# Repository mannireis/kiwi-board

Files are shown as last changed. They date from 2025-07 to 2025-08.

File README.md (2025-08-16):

# Kiwi Board

Screenshot 2025-08-16 at 12-41-57 471098307-857b4444-1be0-49bc-9b43-69fed2567859 png (PNG Image 1916 × 1100 pixels)

The Kiwi Board is a 42-key split keyboard designed for stenographic input. It features a 3×6 column-staggered layout with 3 thumb keys per side.  
The design is based on the [Polyglot keyboard](https://stenokeyboards.com/products/polyglot-keyboard) and includes an integrated RP2040 microcontroller.

This project started after I discovered steno and wanted to build a keyboard tailored for learning and experimenting with chorded input.

---

## Specifications

- Layout: Split, 3×6 + 3 thumb keys per side
- Total keys: 42
- Switches: MX
- Microcontroller: RP2040 (integrated)
- Firmware: [RMK](https://rmk.rs/) — A feature-rich Rust keyboard firmware
- Intended use: Compatible with steno software (e.g. [Plover](https://www.openstenoproject.org/plover/))

---

## Images

### PCB




### Schematic



### Case
kiwi-top
kiwi-side
kiwi-closeup
kiwi-angled

---

## Bill of Materials (BOM)

| Item | Price | Notes |
|---|---|---|
| PCB | $83.78  | Ordered from JLCPCB |
| Keycaps | $9.90 | [AliExpress link](https://shorturl.at/fVK32) |
| Rubber Feet  | $3.84 | [AliExpress link](https://shorturl.at/bqHlW) |
| Switches | $32.72  | [Deltakey Co.](https://deltakeyco.com/) |
| diodes |  | i own them |
| hotswap sockets |  | i have them |
| **Total** | **$130.24** | |

---

## Firmware

The Kiwi Board uses [RMK](https://rmk.rs/), A feature-rich Rust keyboard firmware!

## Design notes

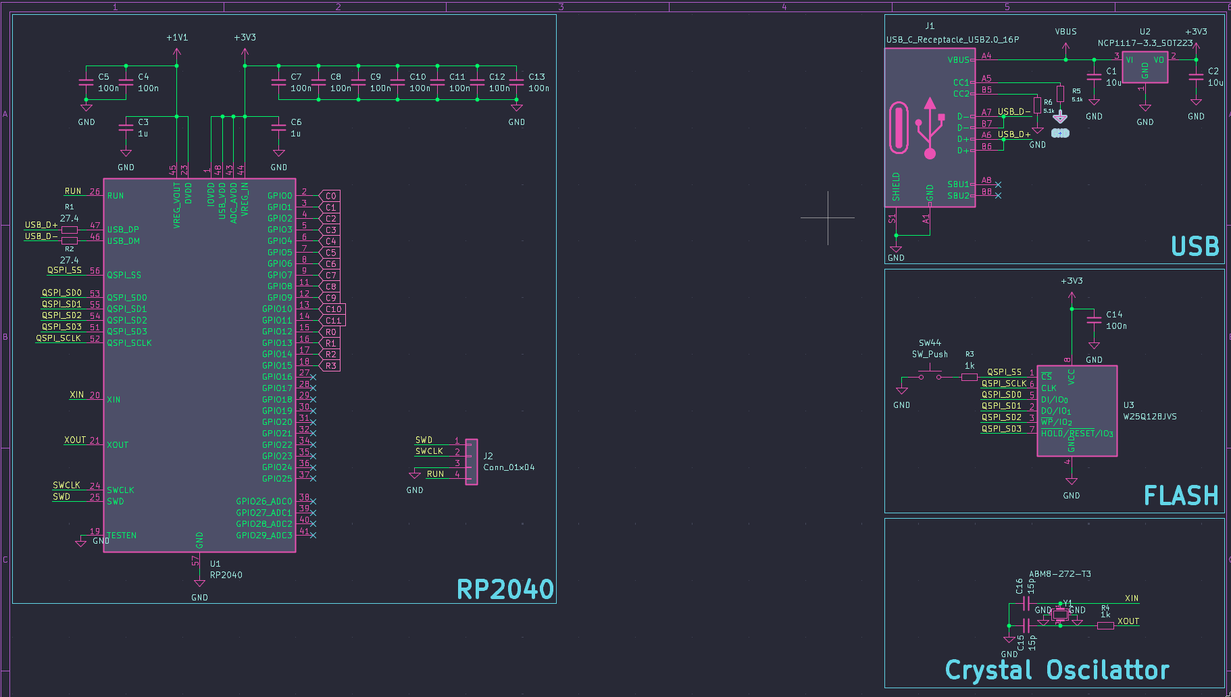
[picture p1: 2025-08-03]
images/screenshot_2025-08-03_11:39:18.png

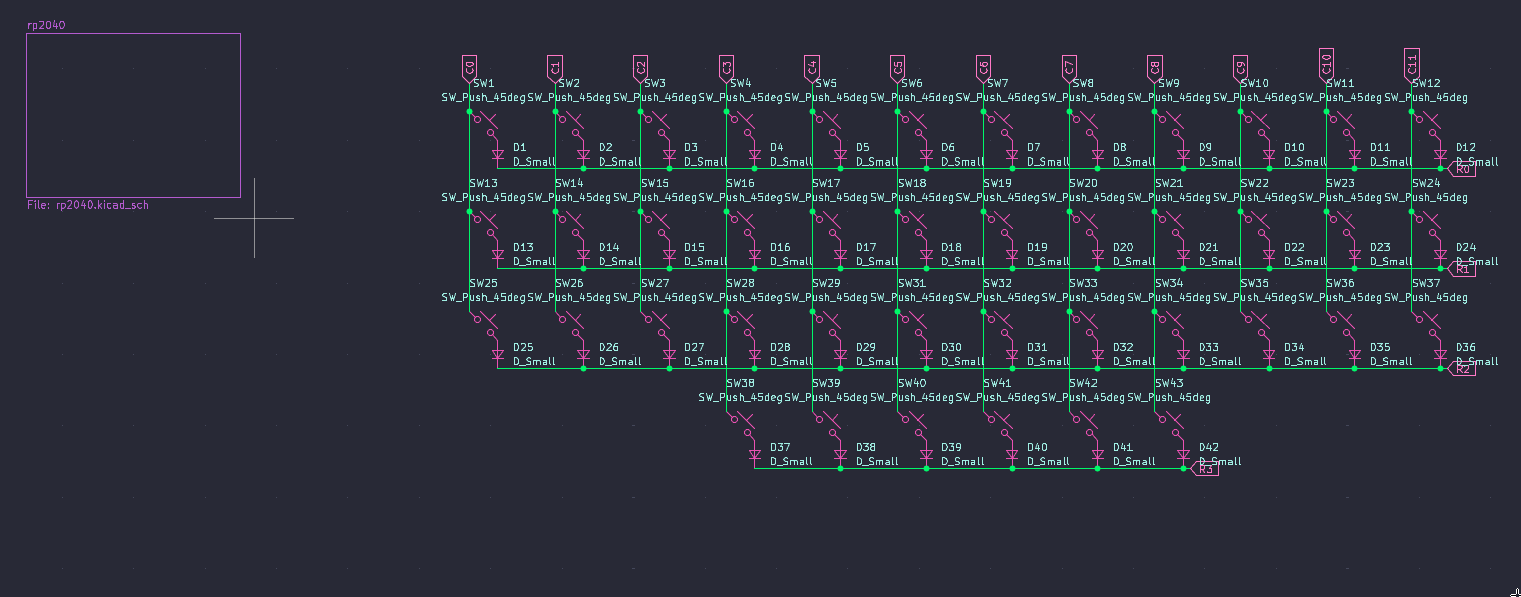
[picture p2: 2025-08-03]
images/screenshot_2025-08-03_11:38:56.png

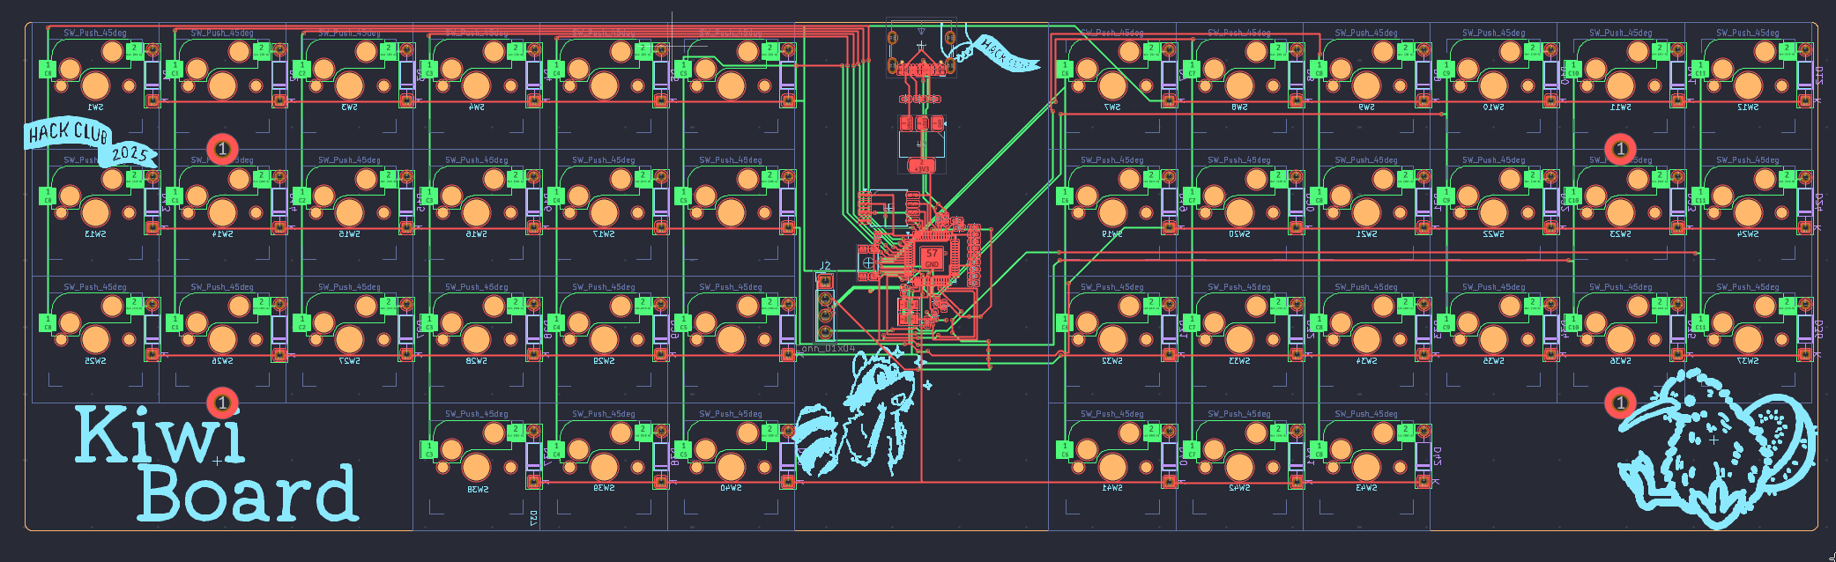
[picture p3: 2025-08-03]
images/screenshot_2025-08-03_11:39:56.png

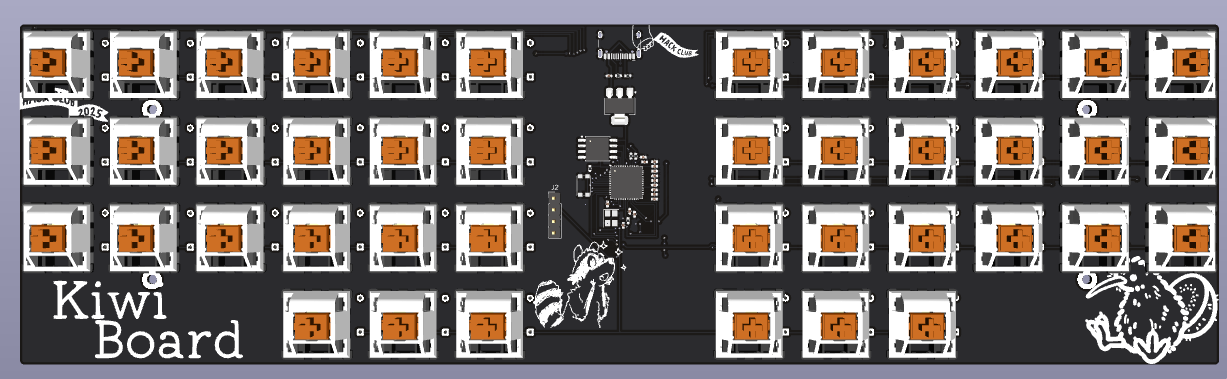
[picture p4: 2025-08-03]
images/screenshot_2025-08-03_11:41:46.png

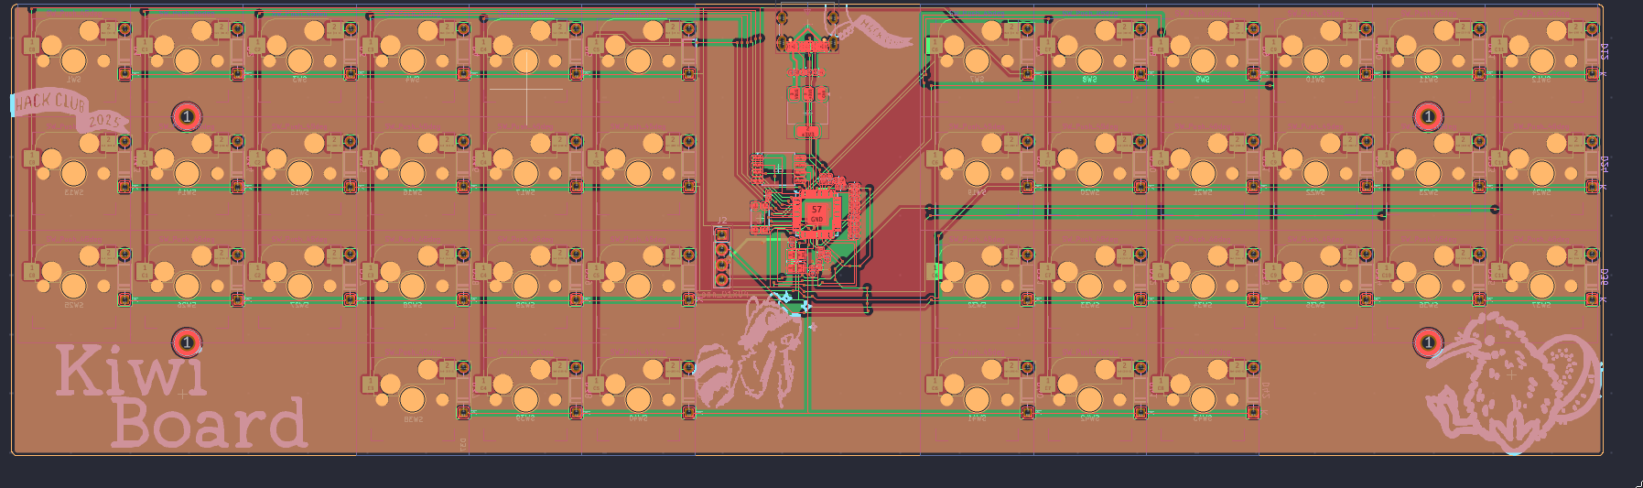
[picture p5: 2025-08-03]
images/screenshot_2025-08-03_11:38:51.png

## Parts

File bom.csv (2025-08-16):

Item | Price | Notes
PCB | $83.78 | from jlcpcb
Keycaps | $9.90 | https://shorturl.at/fVK32
Rubber feet | $3.84 | https://shorturl.at/bqHlW
Switches | $32.72 | https://deltakeyco.com/
Diodes |  | I own them
Hotswap sockets |  | I own them
Total | $130.24

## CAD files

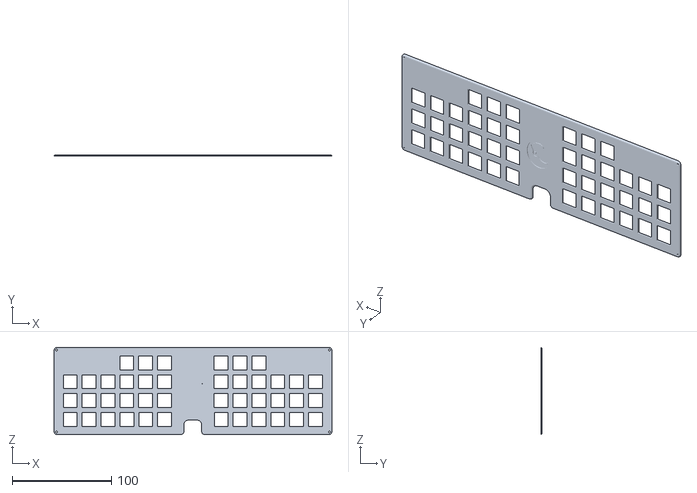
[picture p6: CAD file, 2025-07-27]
3D/kiwi-board-plate.stl
280.8 x 1.50 x 88.0

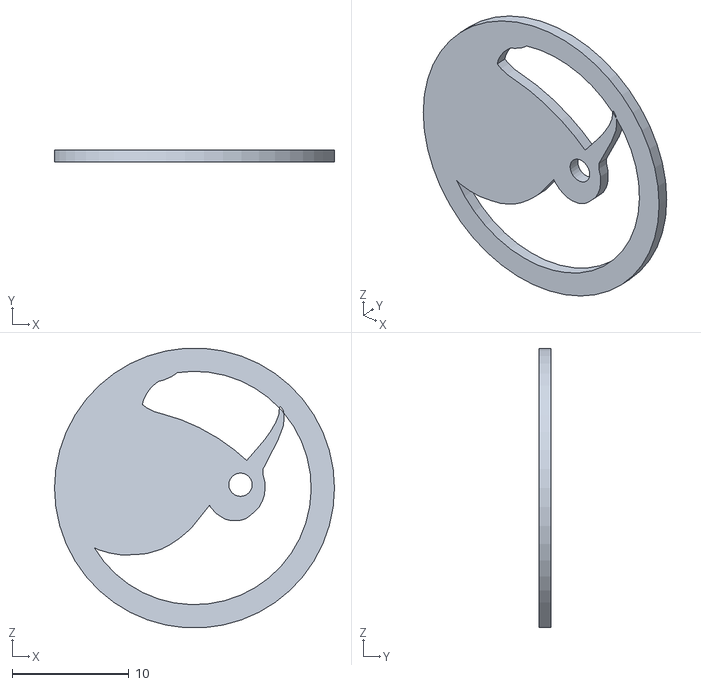
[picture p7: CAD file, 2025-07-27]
3D/kiwi-board-kiwi.stl
24.0 x 1.00 x 23.9

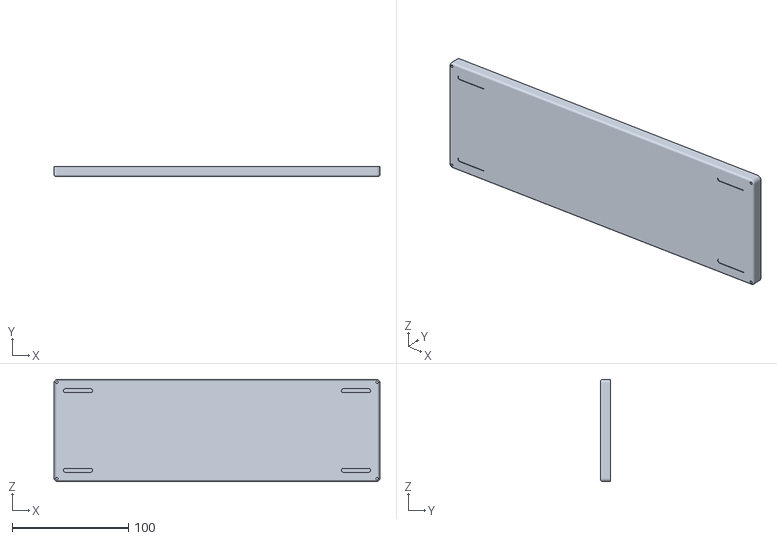
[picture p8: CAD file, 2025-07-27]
3D/kiwi-board-bottom.stl
280.7 x 8.50 x 88.0

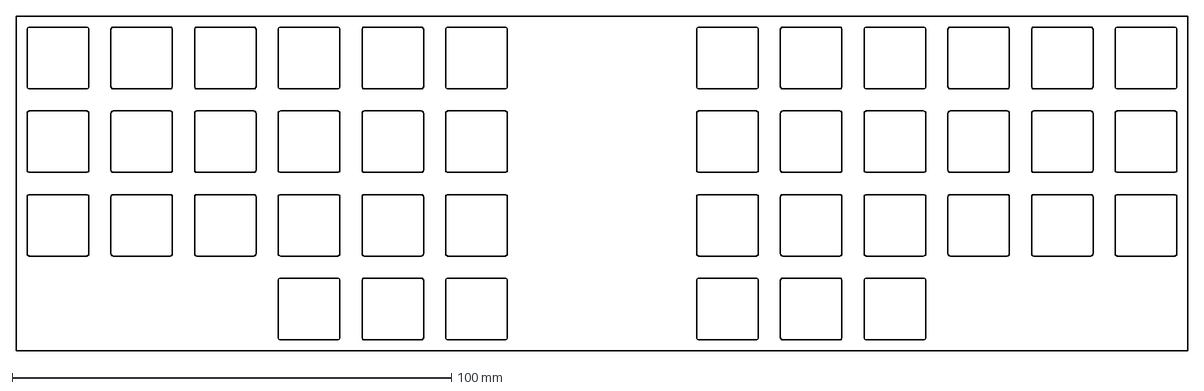
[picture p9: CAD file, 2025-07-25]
3D/plate-2025-07-25T10_07_36.968Z.dxf
266.7 x 76.2 mm

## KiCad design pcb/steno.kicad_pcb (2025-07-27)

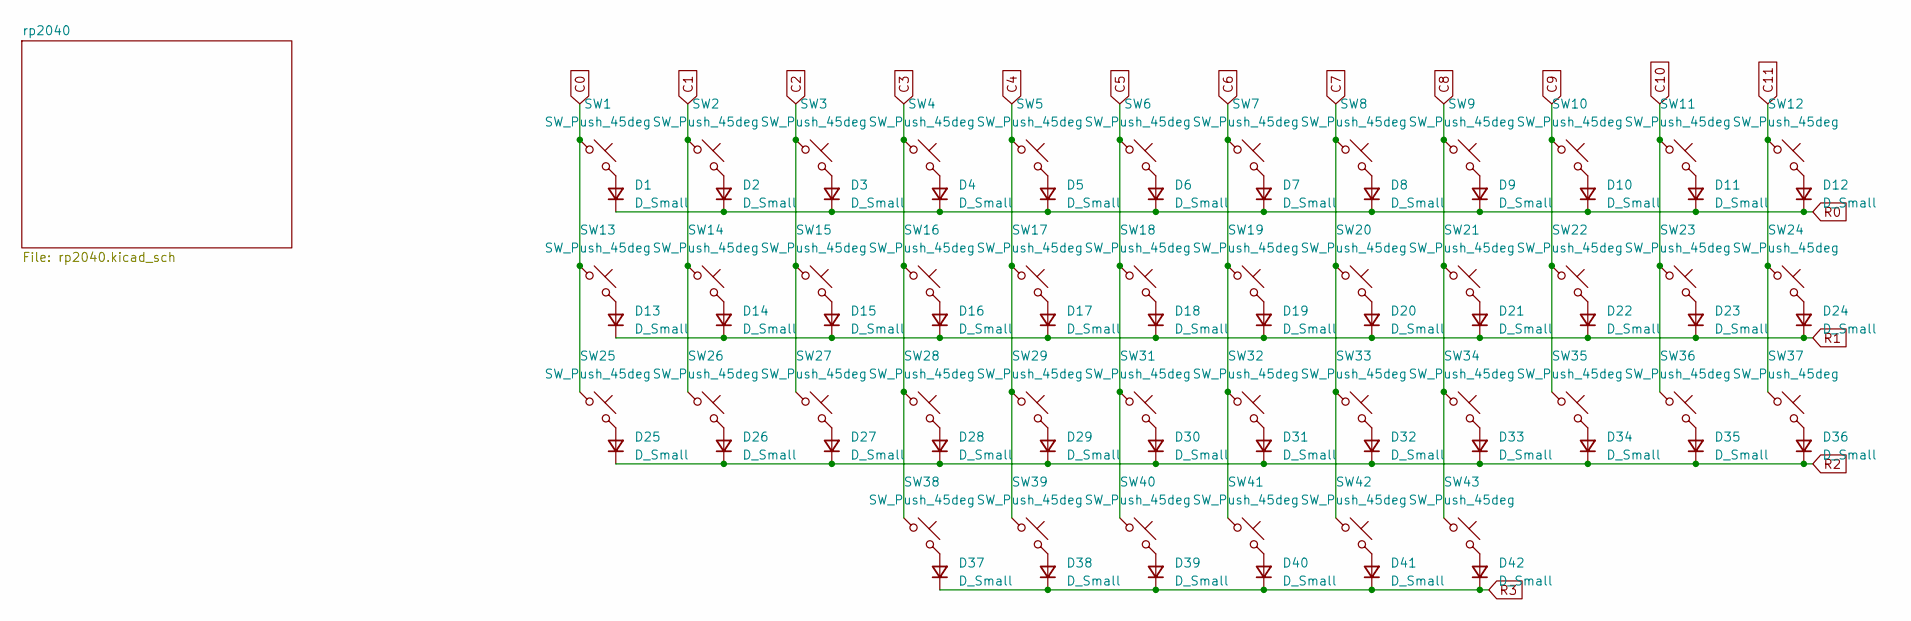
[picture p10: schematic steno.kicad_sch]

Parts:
D1, D2, D3, D4, D5, D6, D7, D8, D9, D10, D11, D12, D13, D14, D15, D16, D17, D18, D19, D20, D21, D22, D23, D24, D25, D26, D27, D28, D29, D30, D31, D32, D33, D34, D35, D36, D37, D38, D39, D40, D41, D42: D_Small; D_DO-35_SOD27_P7.62mm_Horizontal
SW1, SW2, SW3, SW4, SW5, SW6, SW7, SW8, SW9, SW10, SW11, SW12, SW13, SW14, SW15, SW16, SW17, SW18, SW19, SW20, SW21, SW22, SW23, SW24, SW25, SW26, SW27, SW28, SW29, SW31, SW32, SW33, SW34, SW35, SW36, SW37, SW38, SW39, SW40, SW41, SW42, SW43: SW_Push_45deg; MX-Hotswap-1U

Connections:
C0: SW1.1, SW13.1, SW25.1; also elsewhere on the board
C1: SW2.1, SW14.1, SW26.1; also elsewhere on the board
C2: SW3.1, SW15.1, SW27.1; also elsewhere on the board
C3: SW4.1, SW16.1, SW28.1, SW38.1; also elsewhere on the board
C4: SW5.1, SW17.1, SW29.1, SW39.1; also elsewhere on the board
C5: SW6.1, SW18.1, SW31.1, SW40.1; also elsewhere on the board
C6: SW7.1, SW19.1, SW32.1, SW41.1; also elsewhere on the board
C7: SW8.1, SW20.1, SW33.1, SW42.1; also elsewhere on the board
C8: SW9.1, SW21.1, SW34.1, SW43.1; also elsewhere on the board
C9: SW10.1, SW22.1, SW35.1; also elsewhere on the board
C10: SW11.1, SW23.1, SW36.1; also elsewhere on the board
C11: SW12.1, SW24.1, SW37.1; also elsewhere on the board
unnamed: D1.2 (A), SW1.2
unnamed: D2.2 (A), SW2.2
unnamed: D3.2 (A), SW3.2
unnamed: D4.2 (A), SW4.2
unnamed: D5.2 (A), SW5.2
unnamed: D6.2 (A), SW6.2
unnamed: D7.2 (A), SW7.2
unnamed: D8.2 (A), SW8.2
unnamed: D9.2 (A), SW9.2
unnamed: D10.2 (A), SW10.2
unnamed: D11.2 (A), SW11.2
unnamed: D12.2 (A), SW12.2
unnamed: D13.2 (A), SW13.2
unnamed: D14.2 (A), SW14.2
unnamed: D15.2 (A), SW15.2
unnamed: D16.2 (A), SW16.2
unnamed: D17.2 (A), SW17.2
unnamed: D18.2 (A), SW18.2
unnamed: D19.2 (A), SW19.2
unnamed: D20.2 (A), SW20.2
unnamed: D21.2 (A), SW21.2
unnamed: D22.2 (A), SW22.2
unnamed: D23.2 (A), SW23.2
unnamed: D24.2 (A), SW24.2
unnamed: D25.2 (A), SW25.2
unnamed: D26.2 (A), SW26.2
unnamed: D27.2 (A), SW27.2
unnamed: D28.2 (A), SW28.2
unnamed: D29.2 (A), SW29.2
unnamed: D30.2 (A), SW31.2
unnamed: D31.2 (A), SW32.2
unnamed: D32.2 (A), SW33.2
unnamed: D33.2 (A), SW34.2
unnamed: D34.2 (A), SW35.2
unnamed: D35.2 (A), SW36.2
unnamed: D36.2 (A), SW37.2
unnamed: D37.2 (A), SW38.2
unnamed: D38.2 (A), SW39.2
unnamed: D39.2 (A), SW40.2
unnamed: D40.2 (A), SW41.2
unnamed: D41.2 (A), SW42.2
unnamed: D42.2 (A), SW43.2
R0: D1.1 (K), D2.1 (K), D3.1 (K), D4.1 (K), D5.1 (K), D6.1 (K), D7.1 (K), D8.1 (K), D9.1 (K), D10.1 (K), D11.1 (K), D12.1 (K); also elsewhere on the board
R1: D13.1 (K), D14.1 (K), D15.1 (K), D16.1 (K), D17.1 (K), D18.1 (K), D19.1 (K), D20.1 (K), D21.1 (K), D22.1 (K), D23.1 (K), D24.1 (K); also elsewhere on the board
R2: D25.1 (K), D26.1 (K), D27.1 (K), D28.1 (K), D29.1 (K), D30.1 (K), D31.1 (K), D32.1 (K), D33.1 (K), D34.1 (K), D35.1 (K), D36.1 (K); also elsewhere on the board
R3: D37.1 (K), D38.1 (K), D39.1 (K), D40.1 (K), D41.1 (K), D42.1 (K); also elsewhere on the board

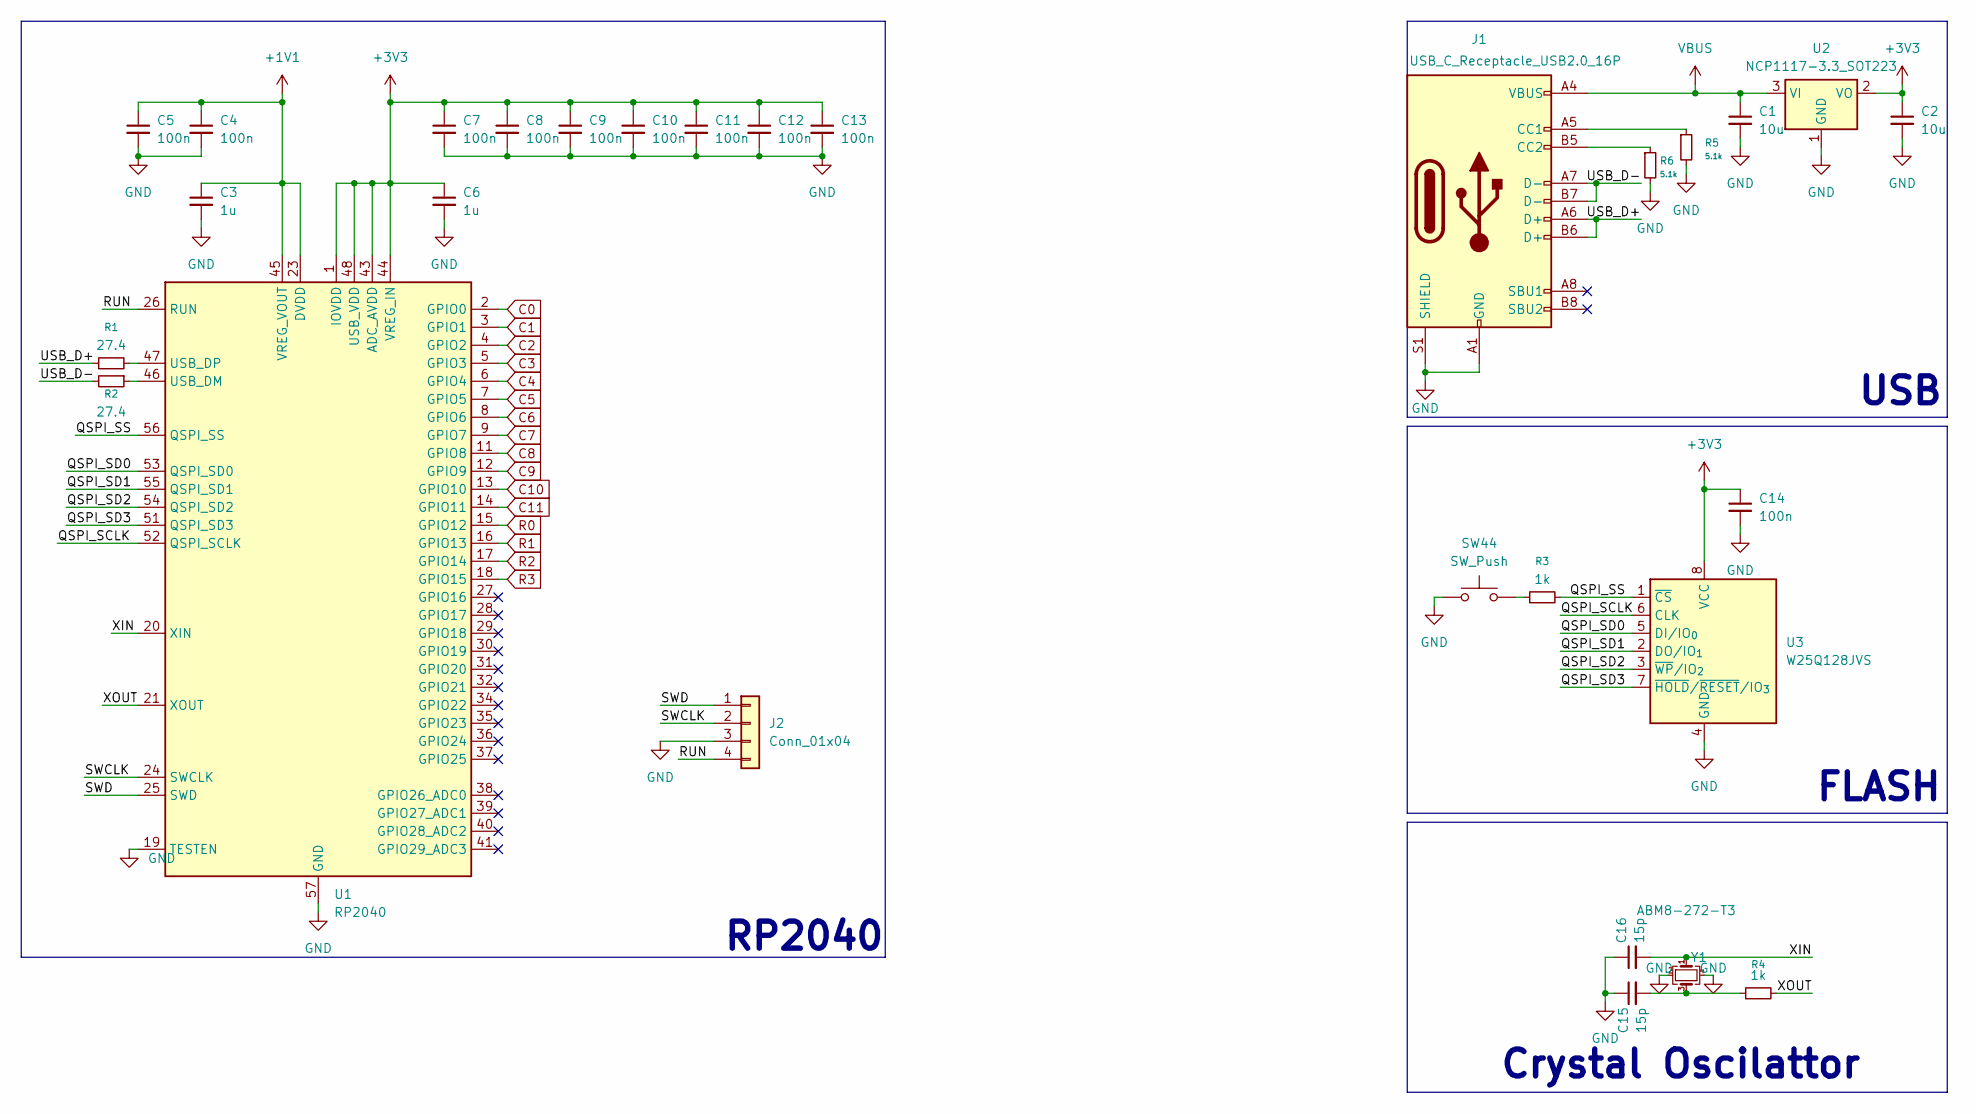
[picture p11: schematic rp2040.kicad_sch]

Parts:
C1, C2: 10u; C_0402_1005Metric
C3, C6: 1u; C_0402_1005Metric
C4, C5, C7, C8, C9, C10, C11, C12, C13, C14: 100n; C_0402_1005Metric
C15, C16: 15p; C_0402_1005Metric
J1: USB_C_Receptacle_USB2.0_16P; USB_C_Receptacle_HCTL_HC-TYPE-C-16P-01A
J2: Conn_01x04; PinHeader_1x04_P2.54mm_Vertical
R1, R2: 27.4; R_0402_1005Metric
R3, R4: 1k; R_0402_1005Metric
R5, R6: 5.1k; R_0402_1005Metric
SW44: SW_Push; SW_Push_1P1T_NO_CK_KMR2
U1: RP2040; QFN-56-1EP_7x7mm_P0.4mm_EP3.2x3.2mm
U2: NCP1117-3.3_SOT223; SOT-223-3_TabPin2
U3: W25Q128JVS; SOIC-8_5.3x5.3mm_P1.27mm
Y1: ABM8-272-T3; Crystal_SMD_Abracon_ABM8AIG-4Pin_3.2x2.5mm

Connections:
+1V1: C3.1, C4.1, C5.1, U1.23 (DVDD), U1.45 (VREG_VOUT), U1.50 (DVDD)
+3V3: C2.1, C6.1, C7.1, C8.1, C9.1, C10.1, C11.1, C12.1, C13.1, C14.1, U1.1 (IOVDD), U1.10 (IOVDD), U1.22 (IOVDD), U1.33 (IOVDD), U1.42 (IOVDD), U1.43 (ADC_AVDD), U1.44 (VREG_IN), U1.48 (USB_VDD), U1.49 (IOVDD), U2.2 (VO), U3.8 (VCC)
/rp2040/QSPI_SCLK: U1.52 (QSPI_SCLK), U3.6 (CLK)
/rp2040/QSPI_SD0: U1.53 (QSPI_SD0), U3.5 (DI/IO_{0})
/rp2040/QSPI_SD1: U1.55 (QSPI_SD1), U3.2 (DO/IO_{1})
/rp2040/QSPI_SD2: U1.54 (QSPI_SD2), U3.3 (~WP/IO_{2})
/rp2040/QSPI_SD3: U1.51 (QSPI_SD3), U3.7 (~HOLD/~RESET/IO_{3})
/rp2040/QSPI_SS: R3.2, U1.56 (QSPI_SS), U3.1 (~CS)
/rp2040/RUN: J2.4, U1.26 (RUN)
/rp2040/SWCLK: J2.2, U1.24 (SWCLK)
/rp2040/SWD: J2.1, U1.25 (SWD)
/rp2040/USB_D+: J1.A6 (D+), J1.B6 (D+), R1.1
/rp2040/USB_D-: J1.A7 (D-), J1.B7 (D-), R2.2
/rp2040/XIN: C16.2, U1.20 (XIN), Y1.1
/rp2040/XOUT: R4.2, U1.21 (XOUT)
C0: U1.2 (GPIO0); also elsewhere on the board
C1: U1.3 (GPIO1); also elsewhere on the board
C2: U1.4 (GPIO2); also elsewhere on the board
C3: U1.5 (GPIO3); also elsewhere on the board
C4: U1.6 (GPIO4); also elsewhere on the board
C5: U1.7 (GPIO5); also elsewhere on the board
C6: U1.8 (GPIO6); also elsewhere on the board
C7: U1.9 (GPIO7); also elsewhere on the board
C8: U1.11 (GPIO8); also elsewhere on the board
C9: U1.12 (GPIO9); also elsewhere on the board
C10: U1.13 (GPIO10); also elsewhere on the board
C11: U1.14 (GPIO11); also elsewhere on the board
GND: C1.2, C2.2, C3.2, C4.2, C5.2, C6.2, C7.2, C8.2, C9.2, C10.2, C11.2, C12.2, C13.2, C14.2, C15.1, C16.1, J1.A1 (GND), J1.A12 (GND), J1.B1 (GND), J1.B12 (GND), J1.S1 (SHIELD), J2.3, R5.2, R6.2, SW44.1, U1.19 (TESTEN), U1.57 (GND), U2.1 (GND), U3.4 (GND), Y1.2, Y1.4
unnamed: C15.2, R4.1, Y1.3
unnamed: J1.A5 (CC1), R5.1
unnamed: J1.B5 (CC2), R6.1
unnamed: R3.1, SW44.2
unnamed: R2.1, U1.46 (USB_DM)
unnamed: R1.2, U1.47 (USB_DP)
R0: U1.15 (GPIO12); also elsewhere on the board
R1: U1.16 (GPIO13); also elsewhere on the board
R2: U1.17 (GPIO14); also elsewhere on the board
R3: U1.18 (GPIO15); also elsewhere on the board
VBUS: C1.1, J1.A4 (VBUS), J1.A9 (VBUS), J1.B4 (VBUS), J1.B9 (VBUS), U2.3 (VI)

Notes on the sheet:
USB
FLASH
RP2040
Crystal Oscilattor

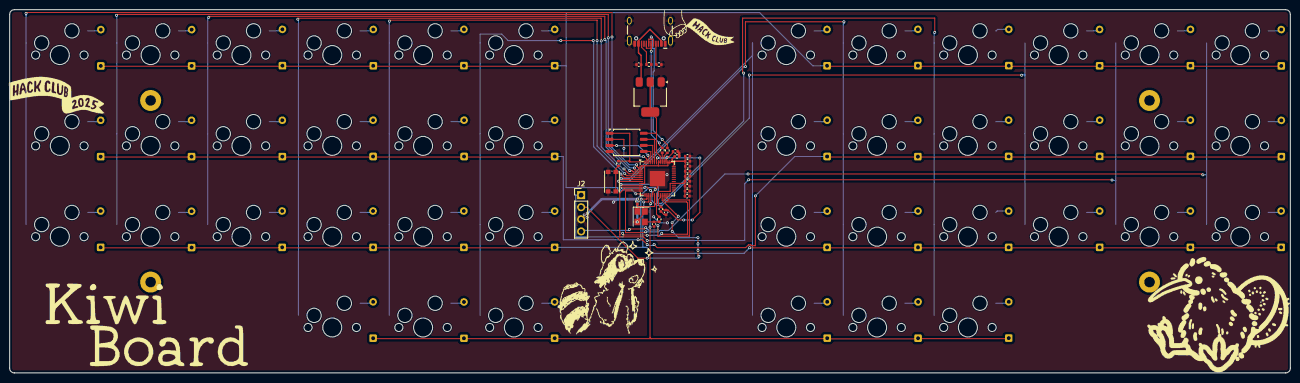
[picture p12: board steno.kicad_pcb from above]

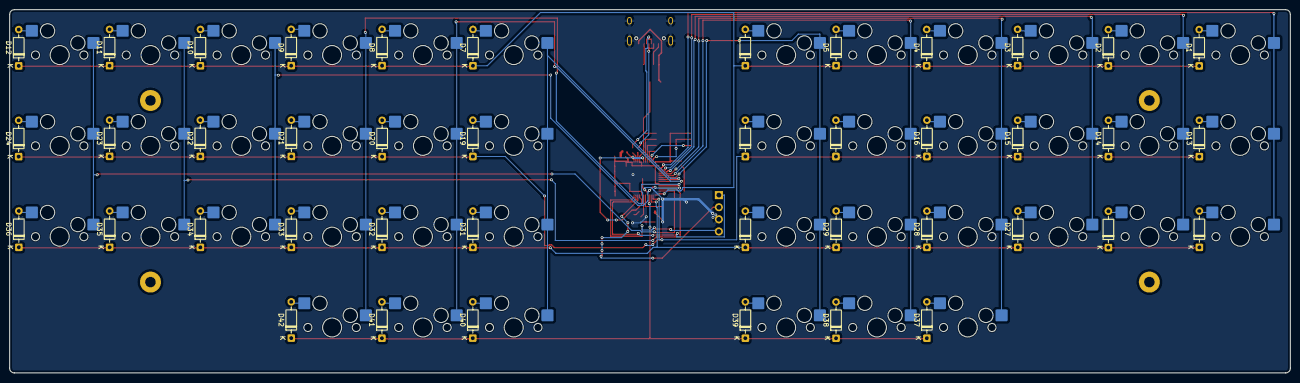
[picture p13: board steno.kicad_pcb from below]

Board: 2 copper layers, 268.7 x 76.2 mm, 113 parts (84 on the bottom side), 81 nets.

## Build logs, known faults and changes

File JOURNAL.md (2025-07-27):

---
title: "Kiwi Board"
author: "Manni"
description: "A 40% stenographic keyboard."
created_at: "2025-07-22"
---

# Total time: 12 hours 25 minutes

## July 22 — 3h 10m

I started by making the schematic, which took about 1 hour since this keyboard is more complex due to the integrated RP2040.

screenshot_2025-07-24_10:33:27  
screenshot_2025-07-24_10:33:15

Then I spent the rest of the time designing the PCB and wiring everything together.

screenshot_2025-07-24_10:35:38  
screenshot_2025-07-24_10:35:49

## July 23 — 45m

I made a few changes to the PCB, such as repositioning some keys and adjusting the RP2040's location.

## July 25 — 3h 30m

I started making the case. I designed the plate and began working on the bottom half!

  


## July 26 — 2h

I finished the case — it turned out really cool and feels quite good, I think!

kbkey  
b4e9ba37-d7e5-4096-9b14-b28c0c6704ea

## July 27 — 3h

I fixed the USB setup since I had used a USB-C plug instead of a receptacle. I also added some header pins for debugging!

**Fixed PCB:**  
screenshot_2025-07-27_17:54:30

Also made a bare working firmware!!!

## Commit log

2025-07-24 add JOURNAL and write JOURNAL
    [nrf.kicad_sch, rp2040.kicad_sch, steno.kicad_pcb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]
2025-07-26 Add 3D files!
    Finished my case fuck yeah
    [kiwi-board-bottom.stl, kiwi-board-kiwi.stl, kiwi-board-plate.stl]
2025-07-27 add pcb stuff
    [rp2040.kicad_sch, steno.kicad_pcb]
2025-07-27 add firmware
    [rp2040.kicad_sch, steno.kicad_pcb]
